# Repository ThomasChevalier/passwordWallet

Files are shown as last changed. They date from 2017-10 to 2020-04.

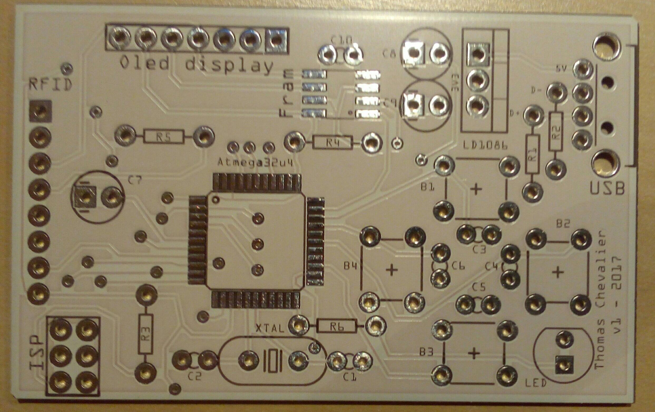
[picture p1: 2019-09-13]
Doc/PCB/photo0.jpeg

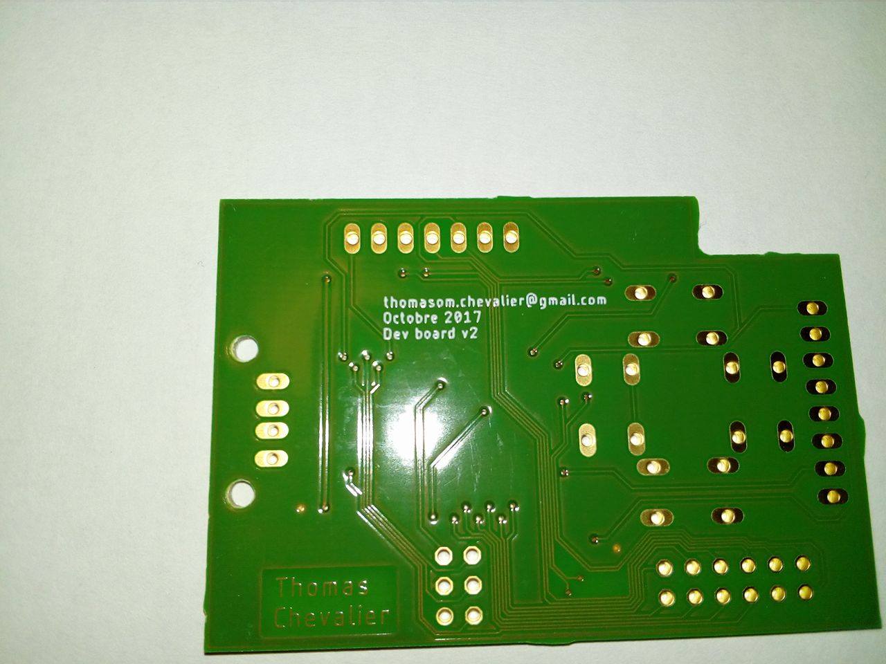
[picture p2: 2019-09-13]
Doc/PCB/received_1699343100099130.jpeg

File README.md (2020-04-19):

# Password Wallet


Password Wallet is a physical password manager, working on every platforms by emulating an HID keyboard to interface with the computer.



## Description

Password Wallet is a USB device that can store credentials (passwords and user names) securely. The manipulation of the stored data as well as the various actions of restitution are available directly on the device which makes it an autonomous object, in the sense that a software is not necessary to use it. The device is designed to be reliable and robust, taking into account the sensitivity of the stored information. This project is what we could call a hardware password manager.
This object differs from software password managers by its portability: it is available on any operating system without prior installation, which facilitates implementation on computers with restricted access. Whereas most password managers offer to save data online to facilitate its transmission, and therefore expose this data to hackers, Password Wallet only stores data in its internal memory, so the identifiers are only gathered in one place, which ensures their security. In addition, its small size, approximately the size of a credit card, allows it to be stored in a pocket or bag.

## Features

* Credentials are AES-128 encrypted
* Unlock it with your RFID card
* Backup mechanism available if your card is lost
* Hardware random number generator based on clock jitter
* Store more than 800 credentials on the same device
* Sort credentials by their name, by date or by number of use
* Add, edit and delete credentials directly with the device
* Generate strong random passwords
* Highly durable memory, using Ferroelectric RAM
* High-contrast display using OLED technology
* Low power usage, maximizing notebook batteries
* Supports Qwerty and Azerty keyboards
* User-proof system, resists to unexpected disconnections
* Desktop application available to communicate with Password Wallet for easier managment

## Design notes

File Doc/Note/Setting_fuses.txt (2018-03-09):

=========================================
             PASSWORD WALLET             
              SETTING FUSES              

Version 1.0 - Last edited on 01/03/18
By Thomas Chevalier (c) 2018
All rights reserved.
=========================================

Introduction
------------

This note shows how to set up the fuses for the atmega32u4

Procedure
---------

* execute :
	avrdude -v {program.verify} -patmega32u4 -cstk500v1 -P/dev/ttyACM0 -b19200 -U lfuse:w:0xff:m -U hfuse:w:0xd0:m -U efuse:w:0xcb:m

Fuses settings
--------------

Low (0xFF) :
	No fuse activated (ext Crystal Osc.; Frequency 8.0-MHz; Start-up time : 16K CK + 65 ms)

High (0xD0) : 
	On chip debug						disabled
	JTAG interface						disabled
	Serial program downloading (SPI)	enabled
	Watchdog time always on				disabled
	Preserve EEPROM through Chip Erase	enabled
	Boot Flash size						2048 words
	Boot reset vector					enabled

Extended (0xCB) :
	Brown-out detection level at VCC = 2.6V

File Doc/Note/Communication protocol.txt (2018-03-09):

=========================================
             PASSWORD WALLET             
           COMMUNICATION PROTOCOL          

Version 1.0 - Last edited on 30/10/17
By Thomas Chevalier (c) 2017
All rights reserved.
=========================================

Introduction
------------

The pc and the device can communicate through a virtual serial port, emulated by the device itself.
The pc send all the command, the device only respond to the command.
Command are shown below.

Description
-----------

The pc is the master of the communication. The device send data only if the pc has sent a command.
A command is constructed as the following :

|--------|----------|--------------|
|   ID   |   SIZE   |     DATA     |
|--------|----------|--------------|
| 1 Byte |  3 Bytes | [Size] bytes |

When the pc send a command the device read the id and the size field and then can execute the command before all the data arrived.
The device always respond to a command by another command. It can be a simple "OK" or a more complex message.
Except for GET_VERSION command the device does not respond to the computer unless it has received the INIT command.

Type of command
---------------

See src/Communication/Commands.h

|-------------------------------|--------|-----------------------------------------------------------------------------------------------------------------------------------------------
|           Command             |   ID   |                                                  Description
|-------------------------------|--------|-----------------------------------------------------------------------------------------------------------------------------------------------
|        Acknowledge (OK)       |  0x00  | The device can respond with an OK command to show that the command has been received and processed without error
|-------------------------------|--------|-----------------------------------------------------------------------------------------------------------------------------------------------
|    Error : not initialized    |  0x01  | The device returns this error if it receives a command without being in communication state
|-------------------------------|--------|-----------------------------------------------------------------------------------------------------------------------------------------------
|       Init communication      |  0x02  | When the device receive this command and the communication is not initialized, it switches to communication state
|-------------------------------|--------|-----------------------------------------------------------------------------------------------------------------------------------------------
|       End communication       |  0x03  | When the device receive this command and the communication is initialized, it switch to main state and end all transfers
|-------------------------------|--------|-----------------------------------------------------------------------------------------------------------------------------------------------
|       Error : Unavaible       |  0x04  | This error indicates that a asked ressource is not available, for example when the computer ask for the key when the device is locked
|-------------------------------|--------|-----------------------------------------------------------------------------------------------------------------------------------------------
|        Error : Bad key        |  0x05  | This error indicates that the computer send the wrong key to unlock the device and therefore the device is still locked
|-------------------------------|--------|-----------------------------------------------------------------------------------------------------------------------------------------------
|            Timeout            |  0x06  | The computer can send this command when the device take too long to respond
|-------------------------------|--------|-----------------------------------------------------------------------------------------------------------------------------------------------
|           Get Fram            |  0x10  | Request the device to send all the content of the fram
|-------------------------------|--------|-----------------------------------------------------------------------------------------------------------------------------------------------
|           Set Fram            |  0x20  | The pc send a fram index and an array of byte and the device must write it to the fram, to address [index]
|-------------------------------|--------|-----------------------------------------------------------------------------------------------------------------------------------------------
|            Get Key            |  0x11  | Request the device to send the main KEY
|-------------------------------|--------|-----------------------------------------------------------------------------------------------------------------------------------------------
|            Set Key            |  0x21  | The pc send 16 byte and the device interpret those byte as the main key (and check the key against the hash)
|-------------------------------|--------|-----------------------------------------------------------------------------------------------------------------------------------------------
|         Get parameter         |  0x12  | Request the device to send the fram identifier followed by a byte set to 0 if STORE_SCREEN_BUFFER_IN_FRAM is not defined, anything else otherwise
|-------------------------------|--------|-----------------------------------------------------------------------------------------------------------------------------------------------
|          Get version          |  0x13  | Request the device to send a byte indicating the internal software version
|-------------------------------|--------|-----------------------------------------------------------------------------------------------------------------------------------------------
|            Fram               |  0x30  | The device sends this command along with the content of the fram, as requested with command GET_FRAM
|-------------------------------|--------|-----------------------------------------------------------------------------------------------------------------------------------------------
|             Key               |  0x31  | The device sends this command along with the content of the key, as requested with command GET_KEY
|-------------------------------|--------|-----------------------------------------------------------------------------------------------------------------------------------------------
|            Param              |  0x32  | The device sends this command along with the parameters, as requested with command GET_PARAM
|-------------------------------|--------|-----------------------------------------------------------------------------------------------------------------------------------------------
|           Version             |  0x33  | The device sends this command along with the version of the software, as requested with command GET_VERSION
|-------------------------------|--------|-----------------------------------------------------------------------------------------------------------------------------------------------

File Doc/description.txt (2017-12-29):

 =========================================
              PASSWORD WALLET             
            MEMORY ORGANIZATION           
 
 Version 1.0 - Last edited on 16/11/17
 By Thomas Chevalier (c) 2017
 All rights reserved.
 =========================================

PASSWORD WALLET
===============

*Périphérique USB autonome pouvant stocker et restituer des identifiants 
informatiques*

# Présentation

Introduction
------------

Password Wallet est un périphérique USB pouvant stocker des identifiants (mots de passe et noms d’utilisateur) de manière sécurisé. La manipulation des données stockées ainsi que les différentes actions de restitution sont disponibles directement sur le périphérique ce qui en fait un objet autonome, dans le sens où un logiciel n’est pas nécessaire pour l’utiliser. Le périphérique se veut fiable et robuste, compte tenu de la sensibilité des informations stockées. Ce projet est ce que l’on pourrait appeler un gestionnaire de mots de passe hardware.
Cet objet se démarque des gestionnaires de mots de passe logiciel par sa portabilité : il est disponible sur n’importe quel système d’exploitation sans installation préalable, ce qui facilite la mise en œuvre sur des ordinateurs dont l’accès est restreint. Là où la plupart des gestionnaires de mots de passes proposent de sauvegarder des données en ligne pour faciliter leur transmission, et par conséquent exposent ces données à des piratages, Password Wallet ne stockent de données que dans sa mémoire interne, les identifiants ne sont donc regroupés que dans un seul endroit, ce qui permet d’assurer leur sécurité. De plus sa petite taille, approximativement celle d’un calepin, permet de le stocker dans sa poche ou dans un sac. Password Wallet combine donc la sécurité par rapport au piratage d’un calepin, et les systèmes de chiffrement des logiciels modernes.

Fonctionnalités
---------------

	* Chiffrement AES-128 des informations
	* Déverrouillage grâce à une carte RFID
	* Récupération et changement de la clef de chiffrement
	* Générateur de nombre aléatoire basé sur la dérive de l’horloge
	* Stockage d’un grand nombre de mot de passe
	* Tri des identifiants possible, alphabétique ou par nombre d’utilisation
	* Ajouter, modifier, supprimer des identifiants depuis le périphérique
	* Génération de mots de passe complètements aléatoires
	* Mémoire à grande durée de vie et robuste
	* Affichage à fort contraste et orientable
	* Faible consommation d’énergie
	* Prise en charge des claviers Qwerty et Azerty
	* Système de récupération en cas de débranchement

Sommaire
--------

Organisation mémoire
Options
Listes de mot de passe

**Nombres aléatoires**

L'appareil propose de générer des nombres complètement aléatoire. En temps normal les ordinateurs ne peuvent générer que des nombres pseudo-aléatoires. En effet nos appareils étant des machines déterministes, la plupart des programmes utilisent des algorithmes au résultat chaotiques pour générer des nombres qui paraissent aléatoire. Cependant une même valeur de départ conduit à une même suite de nombre, et il est théoriquement possible de pouvoir prédire les nombres suivants moyennant un grand échantillon de données. Les nombres produits par Password Wallet sont issus de la dérive entre l'horloge interne du watchdog et l'oscillateur externe. La dérive d'une horloge par rapport à l'autre ne devrait pas se produire dans un monde idéal mais les nombreuses interférences matériel conduisent à un léger décalage d'une horloge par rapport à l'autre. Le watchdog est paramétré pour déclencher une interruption toutes les 16 ms. La valeur de l'octet de poid faible du compteur 1, incrémenté par l'horloge principal, est stocké dans un nombre codé sur 32 bit. Ce dernier est haché avec 32 échantillons consécutif des valeurs enregistrés ("Jenkin's one at a time hash"). Il en résulte la production de deux nombres de 32 bit complètement aléatoire toutes les 1024 ms. La qualité de ces nombres à été testé sur un échantillon d'environ un méga-octet grâce au programme 'ent' fourni par furmilab et grâce à dieharder. Ces deux tests n'ont révélés aucune répétition / corrélation / prédictibilité entre les nombres.

**Carte des sections utilisées**

Les mots de passes sont stockés dans une section de *166 octets* (valeur susceptible de changer à tout instant) chacun. Chaque section utilisé est répertorié dans un tableau situé dans les premières zones de la mémoire. Une section utilisée est notée par un 1 dans cette carte, par un 0 sinon. Ainsi le système peut utiliser de façon optimale la mémoire : l'ajout d'un mot de passe ne se fait pas nécessairement à la fin de la mémoire mais dans la première section disponible. La suppression d'un mot de passe ne nécessite donc pas le décalage de tous les autres mots de passes pour créer une zone contiguë de section utilisé. Il faut noter que cette technique engendre une petite fragmentation de la mémoire mais que celle ci n'est pas gênante dans la mesure les mots de passes forment une liste doublement chaînée entre eux, le temps de parcours est donc constant lorsque le périphérique affiche les mots de passes de façon ordonnée. Le calcul de la taille nécessaire pour la carte des sections utilisé peut s'avérer pénible car la modification de la taille de la carte modifie également l'espace disponible pour stocker les mots de passes (et que j'ai la flemme de mettre ça en équation...).

**Système de récupération**

Le système doit pouvoir résister à toute maladresse de l'utilisateur du fait de son extrême importance. Il n'est pas envisageable de compromettre le stockage des mots de passes ou pire de perdre la clef de chiffrement ou de laisser une partie des mots de passes chiffrées avec une clef différente de celle utilisée pour chiffrer les autres mots de passes. Il faut donc un système robuste de sauvegarde et de récupération des données. Ce système est implémenté par les fichiers "Backup.[ch]". L'idée est de sauvegarder le mot de passe avant de le modifier et de marquer qu'il doit être restauré. Si l'opération réussi il suffit de réinitialiser la section de sauvegarde. Si l'opération échoue alors au prochain démarrage le système détectera qu'il y a eu un problème et restaurera le mot de passe. Le même principe s'applique pour le changement de la clef maître.

** Veille et gestion de l'énergie **

Le périphérique est prévu pour fonctionner sur ordinateur ou bien sur téléphone, il doit donc avoir la consommation la plus faible possible. Un mode veille se met en marche au bout de 15 secondes d'inactivité (valeur par défaut). Ce mode plonge le microcontrôleur dans le mode de veille le plus efficace (SLEEP_MODE_PWR_DOWN) et éteint l'écran, désactive le lecteur rfid, l'USB, la LED et le watchdog. L'ensemble du système consomme alors environ 0.67 mA. Lorsque le système n'est pas en train d'effectuer des calculs le microcontrôleur se met en mode inactif (SLEEP_MODE_IDLE) et consomme alors environ 10 mA. Dans ce mode, le cpu est réveillé toutes les millisecondes et seréactive si un appui sur un bouton est détecté. La durée totale de veille n'excède pas 150ms, ainsi des communications sur le port série peuvent s'effectuer (mise à jour des events toutes les 150ms max). La consommation maximale mesuré est de 30 mA, lors de la recherche de la carte rfid au lancement de l’appareil.

** Identifiants **

Un identifiant est un couple de trois chaînes de caractères : un nom, un nom d’utilisateur et un mot de passe. Chaque identifiant est stocké dans une section de 166 octets, contenant tout d’abord l’adresse du mot de passe précédent suivant un classement par ordre d’utilisation, celle du mot de passe suivant, de même l’adresse du mot de passe précédent suivant un classement alphabétique puis celle du suivant. Ces adresses peuvent être sur un ou deux octets suivant la taille de la mémoire et le nombre de mots de passe qu’elle est capable de stocker. Ensuite le nombre d’utilisation de l’identifiant est stocké sur 2 octets, son nom sur 32 octets (chaîne de caractères ne se finissant pas forcément par un \0), puis le vecteur d’initialisation nécessaire au chiffrement AES-128 CBC du mot de passe sur 16 octets, le mot de passe crypté sur 32 octets, puis l’IV pour le nom d’utilisateur sur 16 octets et enfin le nom d’utilisateur crypté, sur 64 octets. Ces sections sont stockées les unes à la suite des autres dans la mémoire (voir le document décrivant l’organisation de la mémoire).

Identification USB
Communication série
Clavier
Navigation parmi les mots de passes

Barre de progression
Chaînes de caractères
Police de caractère
Orientation de l’écran
Boutons
Fram
Led
Écran
RFID
Auto-test
EEPROM
Options
Changer mot de passe
Changer nom d’utilisateur
Changer nom identifiant
Pas de tri
Tri alphabétique
Tri par utilisation
Changer la clef
Montrer la clef
Forcer une carte
Forcer une clef
Disposition clavier
Orientation de l’écran
Auto-test
Informations système
Formatage
Ajout d’un mot de passe

Récupération
Formatage
Entrer la clef
Forcer une carte

Envoi des informations
Envoi des deux
Envoi du mot de passe
Envoi du nom d’utilisateur
Chiffrement AES
Stockage de la clef sur la carte
Validation de la clef

Timer milliseconde
Infos système

Conversion ascii - keycode
Boucle principale

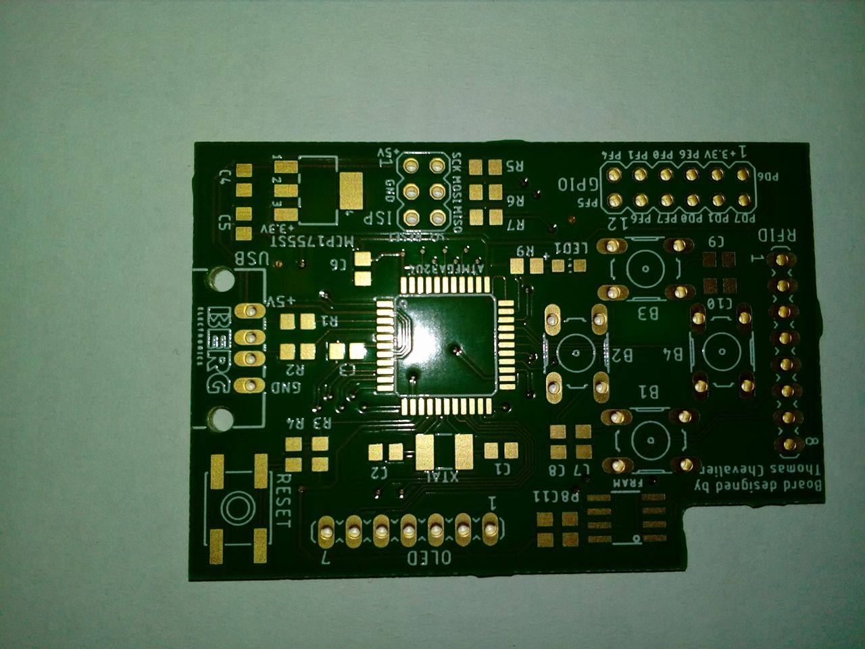
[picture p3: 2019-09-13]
Doc/PCB/received_1699343883432385.jpeg

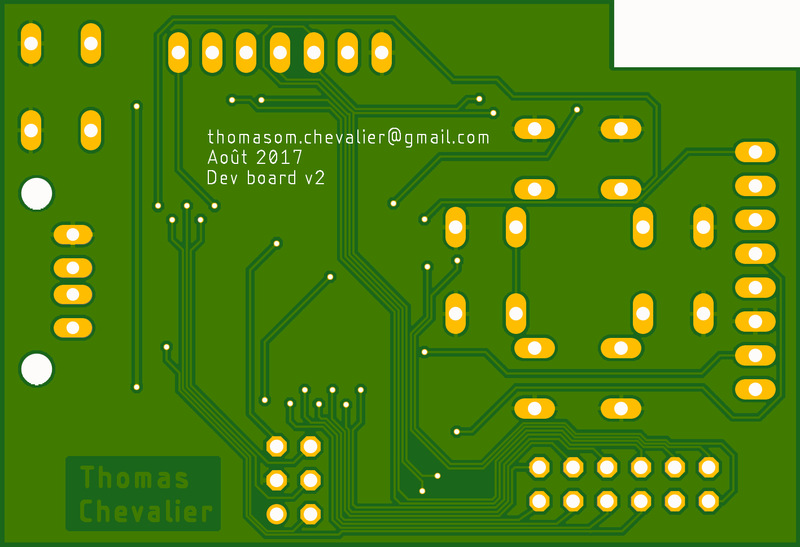
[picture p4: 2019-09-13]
Doc/PCB/copper_bottom.png

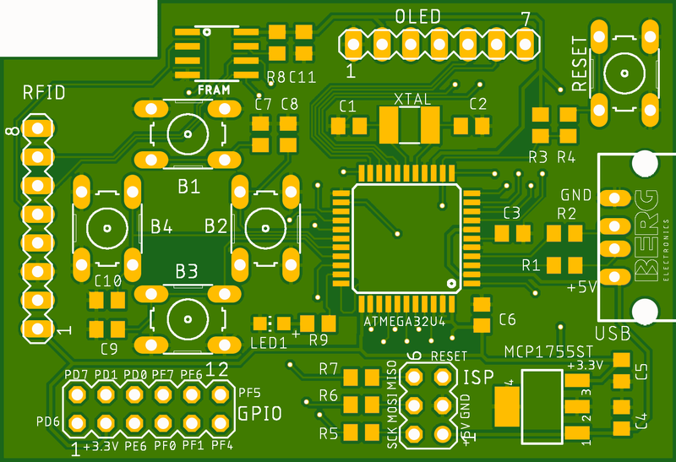
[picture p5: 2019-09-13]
Doc/PCB/copper_top.png

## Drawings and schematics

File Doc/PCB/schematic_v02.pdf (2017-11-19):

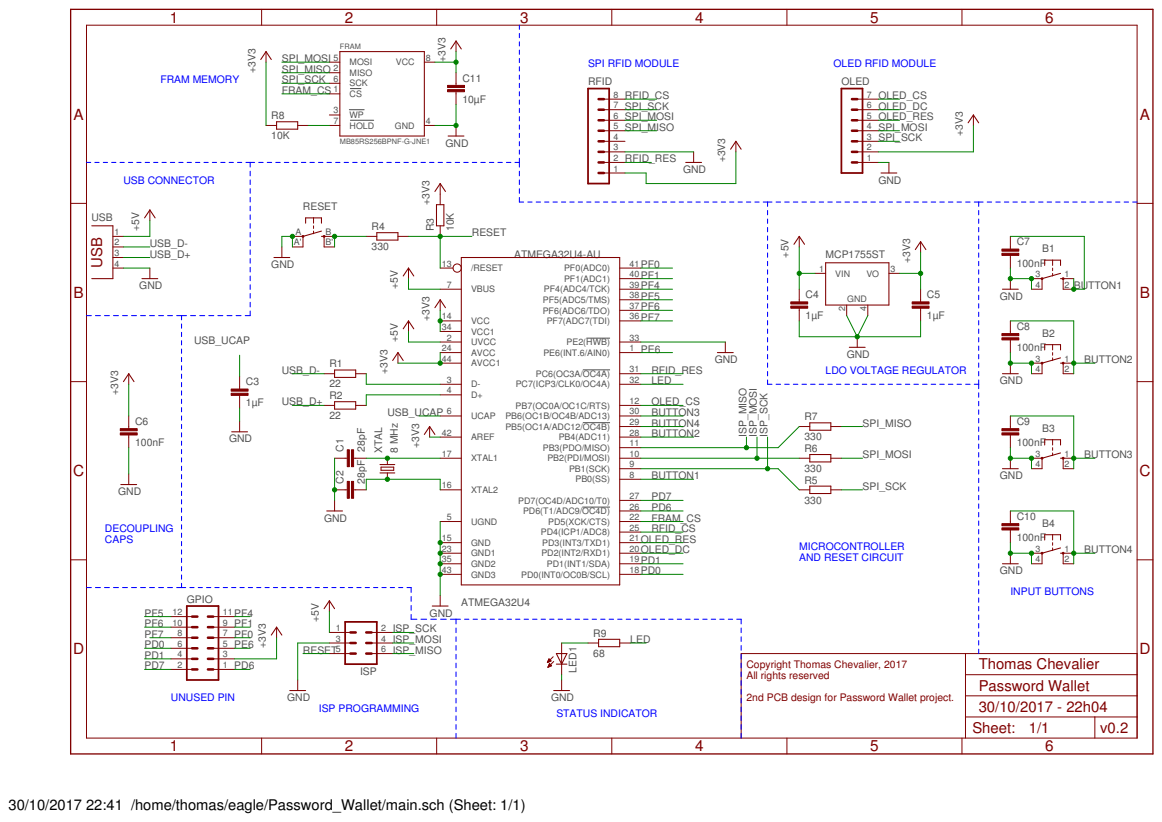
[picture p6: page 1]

All rights reserved
2nd PCB design for Password Wallet project.

30/10/2017 22:41 /home/thomas/eagle/Password_Wallet/main.sch (Sheet: 1/1)

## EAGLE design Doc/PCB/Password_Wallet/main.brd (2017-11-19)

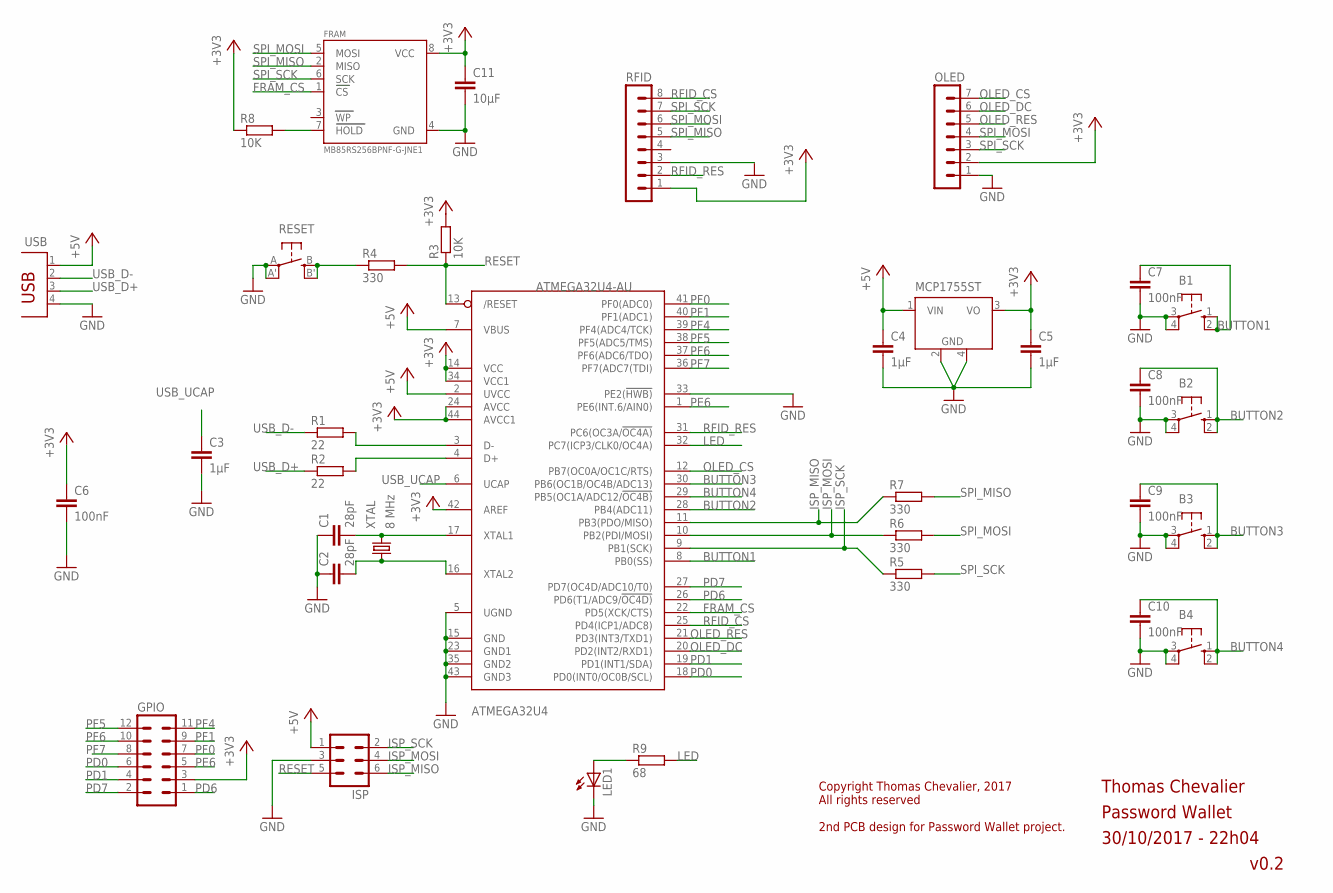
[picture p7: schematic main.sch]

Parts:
ATMEGA32U4: ATMEGA32U4-AU; TQFP44
B1, B2, B3, B4: 10-XX; B3F-10XX
C1, C2: 28pF; C0805
C3, C4, C5: 1µF; C0805
C6, C7, C8, C9, C10: 100nF; C0805
C11: 10µF; C0805
FRAM: MB85RS256BPNF-G-JNE1; SOIC8_150MIL
GPIO: MA06-2
ISP: MA03-2
LED1: LEDCHIP-LED0805; CHIP-LED0805
MCP1755ST: LM2936MP-3.0; SOT223
OLED: MA07-1
R1, R2: 22; R0805
R3, R8: 10K; R0805
R4, R5, R6, R7: 330; R0805
R9: 68; R0805
RESET: SPST_TACT-EVQQ2; EVQ-Q2
RFID: MA08-1
USB: PN87520
XTAL: 8 MHz; 5.0X3.2_2

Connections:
+3V3: ATMEGA32U4.14 (VCC), ATMEGA32U4.24 (AVCC), ATMEGA32U4.34 (VCC1), ATMEGA32U4.42 (AREF), ATMEGA32U4.44 (AVCC1), C5.1, C6.1, C11.1, FRAM.8 (VCC), GPIO.3, MCP1755ST.3 (VO), OLED.2, R3.2, R8.1, RFID.1
+5V: ATMEGA32U4.2 (UVCC), ATMEGA32U4.7 (VBUS), C4.1, ISP.1, MCP1755ST.1 (VIN), USB.1
BUTTON1: ATMEGA32U4.8 (PB0(SS)), B1.1 (S), B1.2 (S1), C7.1
BUTTON2: ATMEGA32U4.28 (PB4(ADC11)), B2.1 (S), B2.2 (S1), C8.1
BUTTON3: ATMEGA32U4.30 (PB6(OC1B/OC4B/ADC13)), B3.1 (S), B3.2 (S1), C9.1
BUTTON4: ATMEGA32U4.29 (PB5(OC1A/ADC12/!OC4B)), B4.1 (S), B4.2 (S1), C10.1
FRAM_CS: ATMEGA32U4.22 (PD5(XCK/CTS)), FRAM.1 (CS)
GND: ATMEGA32U4.5 (UGND), ATMEGA32U4.15 (GND), ATMEGA32U4.23 (GND1), ATMEGA32U4.33 (PE2(!HWB)), ATMEGA32U4.35 (GND2), ATMEGA32U4.43 (GND3), B1.3, B1.4 (P1), B2.3, B2.4 (P1), B3.3, B3.4 (P1), B4.3, B4.4 (P1), C1.1, C2.1, C3.2, C4.2, C5.2, C6.2, C7.2, C8.2, C9.2, C10.2, C11.2, FRAM.4 (GND), ISP.3, LED1.C, MCP1755ST.2 (GND), MCP1755ST.4 (GND), OLED.1, RESET.A, RESET.A' (P1), RFID.3, USB.4
ISP_MISO: ATMEGA32U4.11 (PB3(PDO/MISO)), ISP.6, R7.1
ISP_MOSI: ATMEGA32U4.10 (PB2(PDI/MOSI)), ISP.4, R6.1
ISP_SCK: ATMEGA32U4.9 (PB1(SCK)), ISP.2, R5.1
LED: ATMEGA32U4.32 (PC7(ICP3/CLK0/OC4A)), R9.2
unnamed: ATMEGA32U4.3 (D-), R1.2
unnamed: ATMEGA32U4.17 (XTAL1), C1.2, XTAL.2
unnamed: ATMEGA32U4.4 (D+), R2.2
unnamed: ATMEGA32U4.16 (XTAL2), C2.2, XTAL.1
unnamed: LED1.A, R9.1
unnamed: R4.1, RESET.B (S), RESET.B' (S1)
unnamed: FRAM.7 (HOLD), R8.2
OLED_CS: ATMEGA32U4.12 (PB7(OC0A/OC1C/RTS)), OLED.7
OLED_DC: ATMEGA32U4.20 (PD2(INT2/RXD1)), OLED.6
OLED_RES: ATMEGA32U4.21 (PD3(INT3/TXD1)), OLED.5
PD0: ATMEGA32U4.18 (PD0(INT0/OC0B/SCL)), GPIO.6
PD1: ATMEGA32U4.19 (PD1(INT1/SDA)), GPIO.4
PD6: ATMEGA32U4.26 (PD6(T1/ADC9/!OC4D)), GPIO.1
PD7: ATMEGA32U4.27 (PD7(OC4D/ADC10/T0)), GPIO.2
PE6: ATMEGA32U4.1 (PE6(INT.6/AIN0)), GPIO.5
PF0: ATMEGA32U4.41 (PF0(ADC0)), GPIO.7
PF1: ATMEGA32U4.40 (PF1(ADC1)), GPIO.9
PF4: ATMEGA32U4.39 (PF4(ADC4/TCK)), GPIO.11
PF5: ATMEGA32U4.38 (PF5(ADC5/TMS)), GPIO.12
PF6: ATMEGA32U4.37 (PF6(ADC6/TDO)), GPIO.10
PF7: ATMEGA32U4.36 (PF7(ADC7(TDI)), GPIO.8
RESET: ATMEGA32U4.13 (/RESET), ISP.5, R3.1, R4.2
RFID_CS: ATMEGA32U4.25 (PD4(ICP1/ADC8)), RFID.8
RFID_RES: ATMEGA32U4.31 (PC6(OC3A/!OC4A)), RFID.2
SPI_MISO: FRAM.2 (MISO), R7.2, RFID.5
SPI_MOSI: FRAM.5 (MOSI), OLED.4, R6.2, RFID.6
SPI_SCK: FRAM.6 (SCK), OLED.3, R5.2, RFID.7
USB_D+: R2.1, USB.3
USB_D-: R1.1, USB.2
USB_UCAP: ATMEGA32U4.6 (UCAP), C3.1

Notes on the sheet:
Password Wallet
30/10/2017 - 22h04
v0.2
Thomas Chevalier
Copyright Thomas Chevalier, 2017 All rights reserved 2nd PCB design for Password Wallet project.

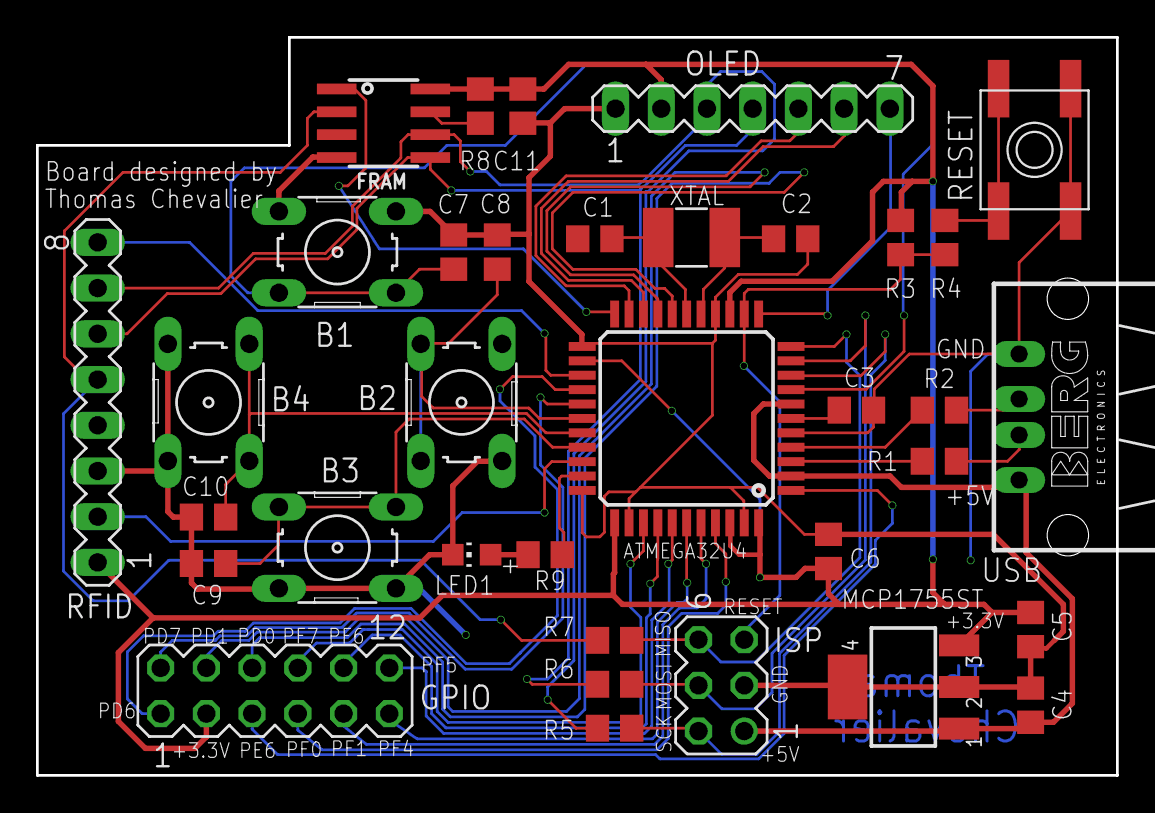
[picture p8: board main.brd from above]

Board: 2 copper layers, 60.0 x 41.0 mm, 35 parts (0 on the bottom side), 42 nets.

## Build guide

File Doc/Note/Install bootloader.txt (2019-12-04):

=========================================
             PASSWORD WALLET             
          UPLOADING BOOTLOADER           

Version 1.0 - Last edited on 30/10/17
By Thomas Chevalier (c) 2017
All rights reserved.
=========================================

Introduction
------------

This note shows how to upload a dfu bootloader on the device.

Procedure
---------

* Go to your lufa directory / Bootloaders / Dfu
* Set up the makefile :
	-MCU          = atmega32u4
	-ARCH         = AVR8
	-BOARD        = NONE
	-F_CPU        = 8000000

	- FLASH_SIZE_KB         = 32
	- BOOT_SECTION_SIZE_KB  = 4
* Make the bootloader
* Connect the device via the isp (Arduino as isp)
* Upload it with the command : avrdude -v {program.verify} -patmega32u4 -cstk500v1 -P/dev/ttyACM0 -b19200 -Uflash:w:"BootloaderDFU.hex":i
* Now you can upload code by typing 'sudo make dfu'

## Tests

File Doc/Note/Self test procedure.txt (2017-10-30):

=========================================
             PASSWORD WALLET             
           SELF TEST PROCEDURE           

Version 1.0 - Last edited on 30/10/17
By Thomas Chevalier (c) 2017
All rights reserved.
=========================================

Introduction
------------

The self test allows the device to test itself to ensure reliable operation.

Description
-----------

See src/Hardware/SelfTest.c

If the lend blink 3 times it indicate a failure for the test, 2 times it indicates a success and 5 times it indicates the beginning of a sequence.
Tests are executed as the following :

1. Begin
	- Led blinks 5 times

2. Oled
	- All pixel on
	- Wait 2 sec
	- All pixel off

3. Fram
	- Read fram id
		- Blink 3 times if failure
		- Blink 2 times if success
	- Wait 0.5 sec

4. Rfid
	- Rfid module is initialized
	- The internal self test is checked
	- Rfid module is powered down
	Result :
		- Blink 3 times if failure
		- Blink 2 times if success
	- Wait 0.5 sec

5. Keyboard
	- Send all the keycode from ' ' to '~'

6. End
	- Led blinks 5 times

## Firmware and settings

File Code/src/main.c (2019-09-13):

#include <avr/interrupt.h>

#include "Globals.h"

#include "System/System.h"
#include "Hardware/Hardware.h"
#include "Security/Security.h"
#include "Program/Program.h"

#include "Security/Encryption.h"
#include "Security/Backup.h"

#include "Hardware/Fram.h"
#include "Hardware/SelfTest.h"
#include "Hardware/Led.h"

#include "USB/USB.h"

#include "FSM/States.h"
#include "FSM/Events.h"

#include "Options/Options_Callback_Advanced.h"

/**
 * @brief Freeze the controller in case of a wrong interrupt
 */
ISR(BADISR_vect)
{
	for (;;)
	{
		led_blink(1);
	}
}

int main(void)
{
	// Read asap the reset register
	uint8_t mcusr = MCUSR;
	MCUSR = 0;

	// Initialization
	system_init();
	hardware_init();
	USB_init();
	security_init();

	// Check the device
	if(self_test_check() == RETURN_ERROR)
	{
		// The device does not behave correctly, freeze it
		while(1){}
	}

	// Read variables from fram and draw the screen
	program_init();

	// Check the reset reason and display it
	system_read_reset_source(mcusr);

	// If the device has not been initialized yet
	const uint8_t optFlag = fram_read_byte(OFFSET_OPTIONS_FLAG);
	if( (optFlag & (1 << OPTIONS_FLAG_OFFSET_INITIALIZED)) == 0)
	{
		opt_callback_full_reset();
	}

	// In case of something goes wrong at the last session,
	// recover broken data.
	backup_recover();

	static const State states[NUM_STATES] =
	{
		{state_wait_card_transition,        state_wait_card_begin,        state_wait_card_end},        // STATE_WAIT_CARD
		{state_main_transition,             state_main_begin,             state_main_end},             // STATE_MAIN
		{state_browse_transition,           state_browse_begin,           state_browse_end},           // STATE_BROWSE
	};

	uint8_t currentStateNum = STATE_WAIT_CARD;
	State const * currentState = &states[currentStateNum];

	currentState->begin();

	while(true)
	{
		program_update();
		uint8_t event = events_get();  // Mask of events

		const uint8_t newState = currentState->transition(event);
		if(currentStateNum != newState)
		{
			currentState->end();
			currentState = &states[newState];
			currentStateNum = newState;
			currentState->begin();
		}

		program_wait();
	}
}

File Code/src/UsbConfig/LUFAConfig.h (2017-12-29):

/*
             LUFA Library
     Copyright (C) Dean Camera, 2015.

  dean [at] fourwalledcubicle [dot] com
           www.lufa-lib.org
*/

/*
  Copyright 2015  Dean Camera (dean [at] fourwalledcubicle [dot] com)

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
  The author disclaims all warranties with regard to this
  software, including all implied warranties of merchantability
  and fitness.  In no event shall the author be liable for any
  special, indirect or consequential damages or any damages
  whatsoever resulting from loss of use, data or profits, whether
  in an action of contract, negligence or other tortious action,
  arising out of or in connection with the use or performance of
  this software.
*/

/** \file
 *  \brief LUFA Library Configuration Header File
 *
 *  This header file is used to configure LUFA's compile time options,
 *  as an alternative to the compile time constants supplied through
 *  a makefile.
 *
 *  For information on what each token does, refer to the LUFA
 *  manual section "Summary of Compile Tokens".
 */

#ifndef _LUFA_CONFIG_H_
#define _LUFA_CONFIG_H_
	
	#include "../Globals.h"

	#if (ARCH == ARCH_AVR8)

		/* Non-USB Related Configuration Tokens: */
//		#define DISABLE_TERMINAL_CODES

		/* USB Class Driver Related Tokens: */
//		#define HID_HOST_BOOT_PROTOCOL_ONLY
//		#define HID_STATETABLE_STACK_DEPTH       {Insert Value Here}
//		#define HID_USAGE_STACK_DEPTH            {Insert Value Here}
//		#define HID_MAX_COLLECTIONS              {Insert Value Here}
//		#define HID_MAX_REPORTITEMS              {Insert Value Here}
//		#define HID_MAX_REPORT_IDS               {Insert Value Here}
//		#define NO_CLASS_DRIVER_AUTOFLUSH

		/* General USB Driver Related Tokens: */
//		#define ORDERED_EP_CONFIG
		#define USE_STATIC_OPTIONS               (USB_DEVICE_OPT_FULLSPEED | USB_OPT_REG_ENABLED | USB_OPT_AUTO_PLL)
		#define USB_DEVICE_ONLY
//		#define USB_HOST_ONLY
//		#define USB_STREAM_TIMEOUT_MS            {Insert Value Here}
//		#define NO_LIMITED_CONTROLLER_CONNECT
//		#define NO_SOF_EVENTS

		/* USB Device Mode Driver Related Tokens: */
//		#define USE_RAM_DESCRIPTORS
		#define USE_FLASH_DESCRIPTORS
//		#define USE_EEPROM_DESCRIPTORS
		#define NO_INTERNAL_SERIAL
		#define FIXED_CONTROL_ENDPOINT_SIZE      8
		#define DEVICE_STATE_AS_GPIOR            2
		#define FIXED_NUM_CONFIGURATIONS         1
//		#define CONTROL_ONLY_DEVICE
// 		#define INTERRUPT_CONTROL_ENDPOINT
		#define NO_DEVICE_REMOTE_WAKEUP
		#define NO_DEVICE_SELF_POWER

		/* USB Host Mode Driver Related Tokens: */
//		#define HOST_STATE_AS_GPIOR              {Insert Value Here}
//		#define USB_HOST_TIMEOUT_MS              {Insert Value Here}
//		#define HOST_DEVICE_SETTLE_DELAY_MS	     {Insert Value Here}
//		#define NO_AUTO_VBUS_MANAGEMENT
//		#define INVERTED_VBUS_ENABLE_LINE

	#elif (ARCH == ARCH_XMEGA)

		/* Non-USB Related Configuration Tokens: */
//		#define DISABLE_TERMINAL_CODES

		/* USB Class Driver Related Tokens: */
//		#define HID_HOST_BOOT_PROTOCOL_ONLY
//		#define HID_STATETABLE_STACK_DEPTH       {Insert Value Here}
//		#define HID_USAGE_STACK_DEPTH            {Insert Value Here}
//		#define HID_MAX_COLLECTIONS              {Insert Value Here}
//		#define HID_MAX_REPORTITEMS              {Insert Value Here}
//		#define HID_MAX_REPORT_IDS               {Insert Value Here}
//		#define NO_CLASS_DRIVER_AUTOFLUSH

		/* General USB Driver Related Tokens: */
		#define USE_STATIC_OPTIONS               (USB_DEVICE_OPT_FULLSPEED | USB_OPT_RC32MCLKSRC | USB_OPT_BUSEVENT_PRIHIGH)
//		#define USB_STREAM_TIMEOUT_MS            {Insert Value Here}
//		#define NO_LIMITED_CONTROLLER_CONNECT
//		#define NO_SOF_EVENTS

		/* USB Device Mode Driver Related Tokens: */
//		#define USE_RAM_DESCRIPTORS
		#define USE_FLASH_DESCRIPTORS
//		#define USE_EEPROM_DESCRIPTORS
//		#define NO_INTERNAL_SERIAL
		#define FIXED_CONTROL_ENDPOINT_SIZE      8
//		#define DEVICE_STATE_AS_GPIOR            {Insert Value Here}
		#define FIXED_NUM_CONFIGURATIONS         1
//		#define CONTROL_ONLY_DEVICE
		#define MAX_ENDPOINT_INDEX               2
//		#define NO_DEVICE_REMOTE_WAKEUP
//		#define NO_DEVICE_SELF_POWER

	#else

		#error Unsupported architecture for this LUFA configuration file.

	#endif
#endif

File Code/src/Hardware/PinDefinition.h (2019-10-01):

/*
 * File generated by pindef_parser.
 * Copyright - Thomas Chevalier - 2017.
 * thomasom.chevalier@gmail.com
 * File created on 01-10-2019 16-35-01
*/

#ifndef PINDEFINITION_HEADER_THOMAS_CHEVALIER
#define PINDEFINITION_HEADER_THOMAS_CHEVALIER

//BUTTON
#define BUTTON_1_PIN_NUM 0
#define BUTTON_1_DDR DDRB
#define BUTTON_1_PORT PORTB
#define BUTTON_1_PIN PINB
#define BUTTON_1_PIN_CHANGE_NUM PCINT0

#define BUTTON_2_PIN_NUM 4
#define BUTTON_2_DDR DDRB
#define BUTTON_2_PORT PORTB
#define BUTTON_2_PIN PINB
#define BUTTON_2_PIN_CHANGE_NUM PCINT4

#define BUTTON_3_PIN_NUM 6
#define BUTTON_3_DDR DDRB
#define BUTTON_3_PORT PORTB
#define BUTTON_3_PIN PINB
#define BUTTON_3_PIN_CHANGE_NUM PCINT6

#define BUTTON_4_PIN_NUM 5
#define BUTTON_4_DDR DDRB
#define BUTTON_4_PORT PORTB
#define BUTTON_4_PIN PINB
#define BUTTON_4_PIN_CHANGE_NUM PCINT5


//FRAM
#define FRAM_CS_PIN_NUM 5
#define FRAM_CS_DDR DDRD
#define FRAM_CS_PORT PORTD
#define FRAM_CS_PIN PIND


//LED
#define LED_PIN_NUM 7
#define LED_DDR DDRC
#define LED_PORT PORTC
#define LED_PIN PINC


//OLED
#define OLED_CS_PIN_NUM 7
#define OLED_CS_DDR DDRB
#define OLED_CS_PORT PORTB
#define OLED_CS_PIN PINB

#define OLED_DC_PIN_NUM 2
#define OLED_DC_DDR DDRD
#define OLED_DC_PORT PORTD
#define OLED_DC_PIN PIND

#define OLED_RES_PIN_NUM 3
#define OLED_RES_DDR DDRD
#define OLED_RES_PORT PORTD
#define OLED_RES_PIN PIND


//RFID
#define RFID_CS_PIN_NUM 4
#define RFID_CS_DDR DDRD
#define RFID_CS_PORT PORTD
#define RFID_CS_PIN PIND

#define RFID_RES_PIN_NUM 6
#define RFID_RES_DDR DDRC
#define RFID_RES_PORT PORTC
#define RFID_RES_PIN PINC


//SPI
#define SPI_SS_PIN_NUM 0
#define SPI_SS_DDR DDRB
#define SPI_SS_PORT PORTB
#define SPI_SS_PIN PINB

#define SPI_SCK_PIN_NUM 1
#define SPI_SCK_DDR DDRB
#define SPI_SCK_PORT PORTB
#define SPI_SCK_PIN PINB

#define SPI_MOSI_PIN_NUM 2
#define SPI_MOSI_DDR DDRB
#define SPI_MOSI_PORT PORTB
#define SPI_MOSI_PIN PINB

#define SPI_MISO_PIN_NUM 3
#define SPI_MISO_DDR DDRB
#define SPI_MISO_PORT PORTB
#define SPI_MISO_PIN PINB


// INIT VALUE
#define DDRB_INIT_VALUE ((1 << OLED_CS_PIN_NUM) | (1 << SPI_SS_PIN_NUM) | (1 << SPI_SCK_PIN_NUM) | (1 << SPI_MOSI_PIN_NUM) | 0)
#define PORTB_INIT_VALUE ((1 << BUTTON_1_PIN_NUM) | (1 << BUTTON_2_PIN_NUM) | (1 << BUTTON_3_PIN_NUM) | (1 << BUTTON_4_PIN_NUM) | (1 << OLED_CS_PIN_NUM) | 0)

#define DDRC_INIT_VALUE ((1 << LED_PIN_NUM) | (1 << RFID_RES_PIN_NUM) | 0)
#define PORTC_INIT_VALUE ((1 << RFID_RES_PIN_NUM) | 0)

#define DDRD_INIT_VALUE ((1 << FRAM_CS_PIN_NUM) | (1 << OLED_DC_PIN_NUM) | (1 << OLED_RES_PIN_NUM) | (1 << RFID_CS_PIN_NUM) | 0)
#define PORTD_INIT_VALUE ((1 << FRAM_CS_PIN_NUM) | (1 << RFID_CS_PIN_NUM) | 0)

#define INIT_ALL_DDR DDRB = DDRB_INIT_VALUE; \
DDRC = DDRC_INIT_VALUE; \
DDRD = DDRD_INIT_VALUE; \

#define INIT_ALL_PORT PORTB = PORTB_INIT_VALUE; \
PORTC = PORTC_INIT_VALUE; \
PORTD = PORTD_INIT_VALUE; \


#endif // PINDEFINITION_HEADER_THOMAS_CHEVALIER

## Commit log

2016-10-20 Add pin definition file
2016-10-21 Add 4th button, update some code
2016-10-21 Spi freeze bug corriged ! Browse menu working
    [main.c]
2016-10-24 Add random generation of printable character
2016-10-27 Fix issue in request_printable
    [main.c]
2016-12-30 Bug fix in fram read id
    [Fram.c]
2016-12-30 Add constant for spi pin id
2017-02-15 Small updates and fix, add Lufa directory
    [LUFAConfig.h, main.c]
2017-02-17 Full integration of LUFA library, device can now work as a keyboard. Refactorisation
2017-02-23 Work on sorting algoritms (not working yet), add useful folder to repository
    [Alphabet to Key code (qwerty).ods, Atmega32u4.fzz, Condensateur 0.1uF.ods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]
2017-02-25 Change directory organisation, add Led files, upload a bootloader on the atmega32u4 (no need to use isp programming anymore), code optimizations, and more ...
2017-03-10 Improve speed of transmission when pc send data to the device
2017-04-10 Add message for reset source, add calls to sorting method
    [System.c, main.c]
2017-07-12 Add I2C fram support. Fix list sorting. Random improvement.
    [Fram.c, I2C.c]
2017-07-15 Syntax fix and refactor desktop app + resolving function
    [main.c]
2017-07-20 Fix font problem. Add pcb dir. Work on desktop app.
    [password_wallet.kicad_pcb, password_wallet.sch]
2017-07-21 Fix random char generation ('~' is now generated), reduce code size
    [main.c]
2017-08-08 Refactor option system. Fix #8
    [main.c]
2017-08-08 Add gpio to reduce code size. Fix #15
    [main.c]
2017-08-08 Group spi setup in one function. Fix #9
    [Fram.c]
2017-08-08 Replace State_Recovery by a list of option
    [main.c]
2017-08-08 Remove no encryption option. Fix #24
    [main.c]
2017-08-09 Add sleep mode. Fix #12
    [PinDefinition.h, System.c]
2017-08-10 Fix wrong attribute in descriptior (self powered)
2017-08-11 Minor change. Add minimal example to the led problem
    [LUFAConfig.h, System.c, main.c]
2017-08-11 Add a new utility to manage the pin attribution. Fix #19. Add doc
    [Fram.c]
2017-08-12 Declare oled data extern to fix #21. Remove '~' (tilde) from the accepted input. On windows the tilde is inserted by pressing two times the key whereas on linux it is inserted when typed one time the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
2017-08-13 Add a backup system. If a reset occurs during the update of a pwd or a usr name the password will be restored to the value before the update; If a reset occurs during the update of the master key the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
    [main.c]
2017-08-14 Add center x option for str. Remove small font. Fix type strings artefacts.
    [System.c, main.c, main.cpp]
2017-08-14 Fix underflow issue in string_parser
    [main.cpp]
2017-08-28 Many changes. Improve code for device, work on gui and on the memory parser. Add lib dir
2017-09-29 Add timeout timer for the serial com. Remove state_communication.
2017-09-30 Remove kicad files
    [password_wallet.kicad_pcb, password_wallet.sch]
2017-10-23 When the screen is reversed, all work well
    [main.c]
2017-10-24 Add key entered event and fix a bug in the desktop app wich lead to an invalid command transmission
    [main.c]
2017-10-30 Changes in note to make them more printable
2017-11-19 Clean folders. Add sample of random data generated by the device
    [Alphabet to Key code (qwerty).ods, Atmega32u4.fzz, Condensateur 0.1uF.ods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]
2018-01-06 Optimize buttons_pressed
    modifié : src/Hardware/Buttons.c
2018-03-01 Add a note on fuses
2018-03-01 Removed unnecessary files from the repo
    [Atmega32u4.fzz, Condensateur 0.1uF.ods, PasswordWalletDevBoard.fzz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]
2018-03-05 Update pins to match the pcb
2018-03-05 Update files to work with the pcb
2018-03-06 Remove loop that force to release buttons and forbid access to pwd menu if no pwd
2018-03-07 Fix a bug in the rfid driver
2018-03-07 Fix a bug in the handling of pwd id. Improve power management
    [Fram.c, System.c]
2018-03-09 Add a program to transfer fram content from the pc to the device
2018-03-09 Add bootloader to the repo. Add a reset command
    [BootloaderDFU.h, LUFAConfig.h, System.c]
2018-12-01 Fix a bug in the backup system that can lead to data loss
    [Fram.c]
2019-09-13 Add pictures of PCB
2019-12-04 Add 'sudo' to write with the bootloader on the device

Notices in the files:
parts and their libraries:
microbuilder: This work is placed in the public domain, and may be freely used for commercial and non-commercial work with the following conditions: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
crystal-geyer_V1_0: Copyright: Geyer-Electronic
